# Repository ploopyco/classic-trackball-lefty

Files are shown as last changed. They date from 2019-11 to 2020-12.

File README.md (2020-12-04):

# The Left-Handed Ploopy Trackball

By some stroke of luck, you've made your way here. The Ploopy Trackball. For left-handed people. Your life will never be the same.

This repository contains all of the design and production files necessary to make a Ploopy Trackball. For left-handed people. We've also included some kick-ass documentation in the Wiki on how to get it made, assemble it, and program it. (It's the same as our documentation for our right-handed trackball. You can find it [here](https://github.com/ploopyco/mouse/wiki).)

What are you waiting for? Your new life awaits.

Did I mention that this is for left-handed people? Because HELL YEAH, it is.

## QMK Firmware

If you're looking for a hex file containing working QMK code with a keymapping compatible with VIA, look in the firmware directory.

## Schematics

Note that the schematics are the same as the right-handed version of this mouse, so the revision number will say RX.XXX, not LX.XXX. This is intentional: the mice are schematically identical, and only the layout of the PCBs is different.

## Under what license is this released?

The firmware is released under GPLv3. The hardware is released under OHL CERN v1.2. Check the respective directories for full license text.

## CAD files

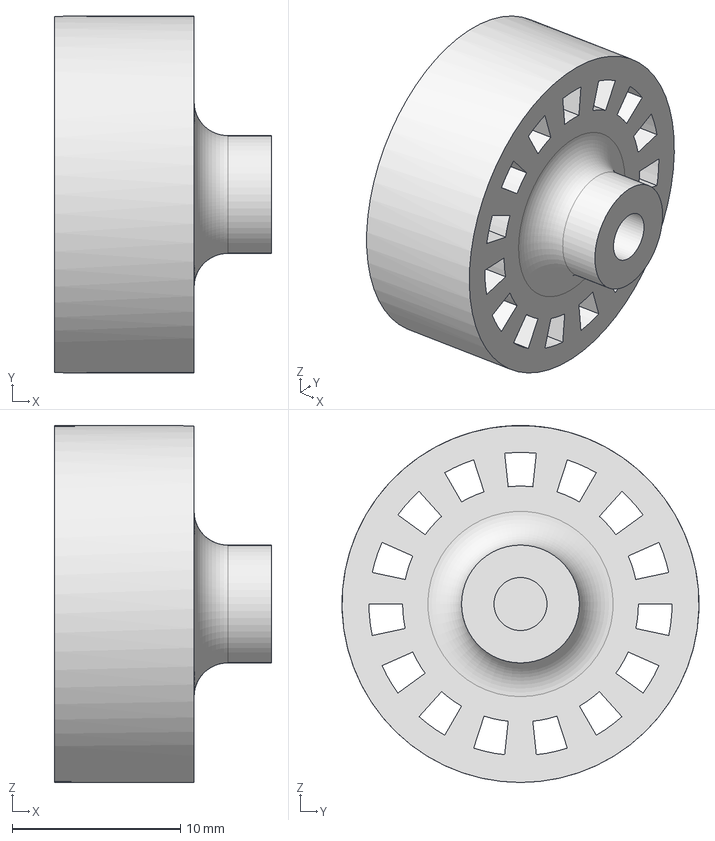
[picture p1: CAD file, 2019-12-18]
hardware/Mechanicals/STEPs/ScrollWheel.stp
12.9 x 21.2 x 21.2 mm

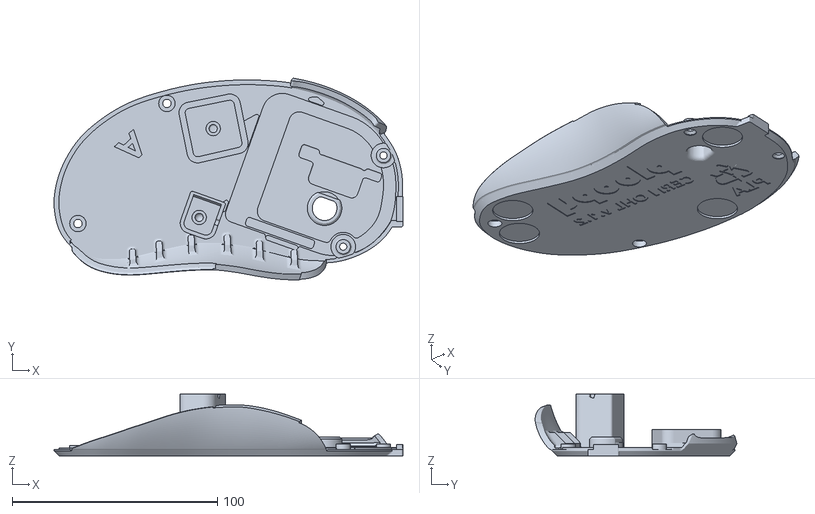
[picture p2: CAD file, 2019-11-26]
hardware/Mechanicals/STLs/Base-Lefty.stl
170.0 x 98.3 x 30.0

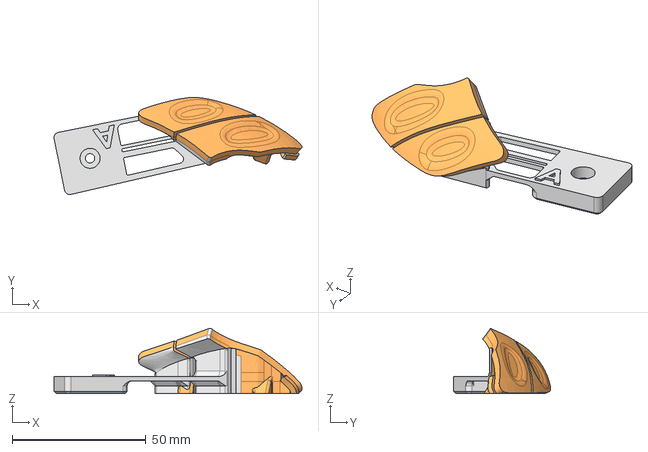
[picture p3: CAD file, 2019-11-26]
hardware/Mechanicals/STEPs/Secondary Buttons-Lefty.stp
92.8 x 36.3 x 24.3 mm

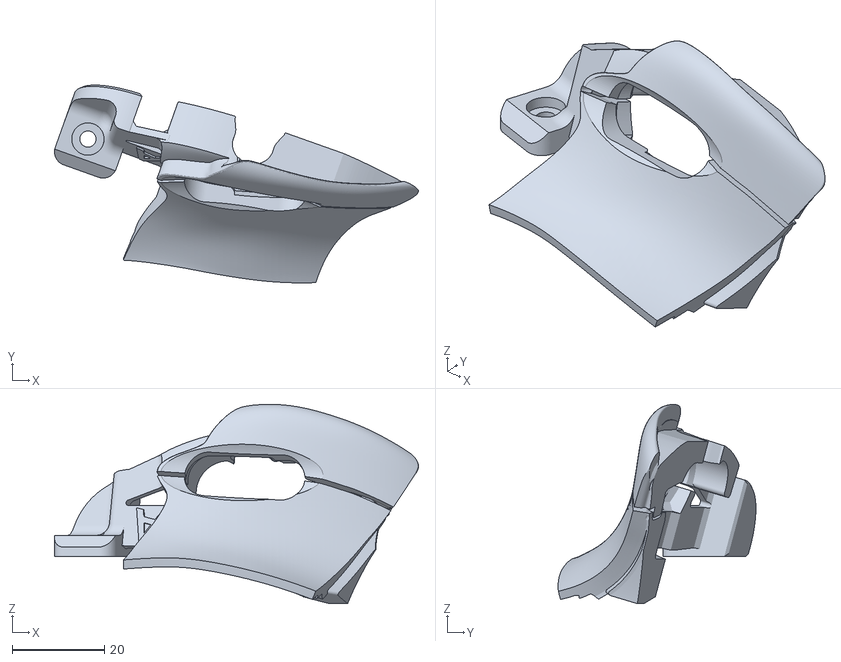
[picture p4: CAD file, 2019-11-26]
hardware/Mechanicals/STLs/Primary Buttons-Lefty.stl
78.9 x 42.9 x 43.2

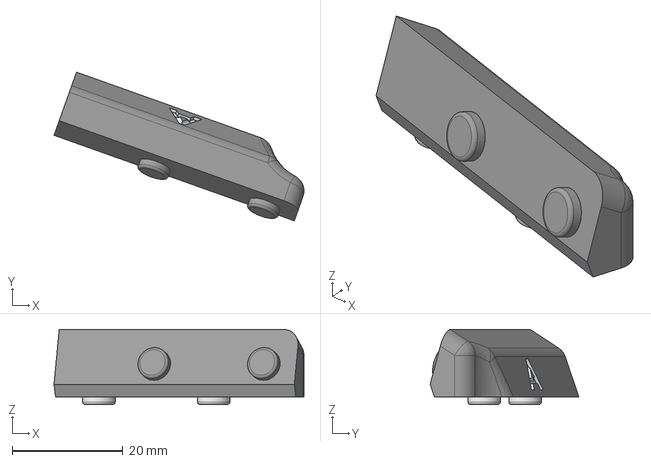
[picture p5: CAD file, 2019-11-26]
hardware/Mechanicals/STEPs/PCB Anchor-Lefty.stp
45.1 x 26.9 x 13.6 mm

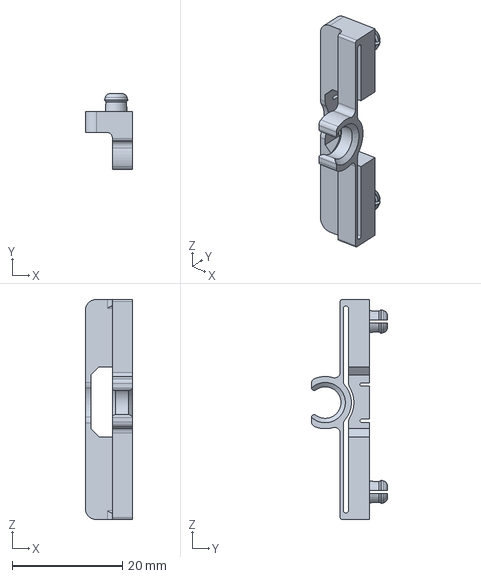
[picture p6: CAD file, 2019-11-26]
hardware/Mechanicals/STEPs/ScrollWheelHolderHolder-Lefty.stp
8.60 x 13.8 x 39.9 mm

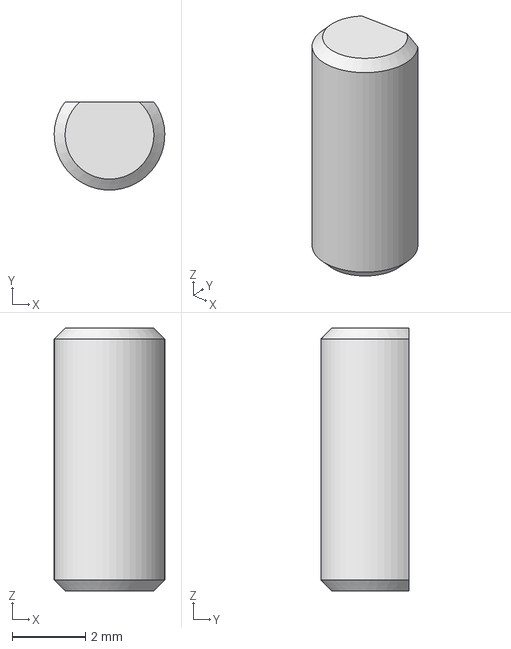
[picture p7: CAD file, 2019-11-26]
hardware/Mechanicals/STEPs/RollerBearingDowel.stp
3.03 x 2.42 x 7.20 mm

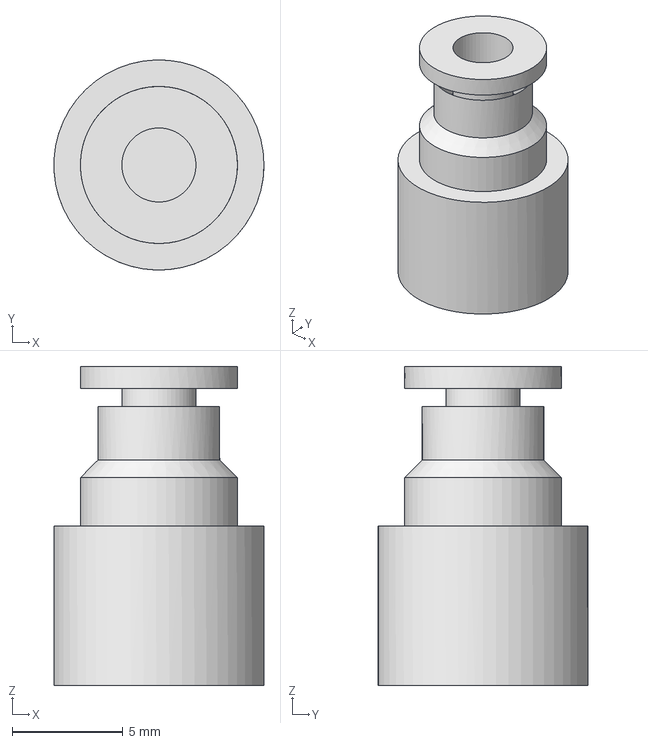
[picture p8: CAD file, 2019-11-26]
hardware/Mechanicals/STEPs/ScrollWheelHolder.stp
9.49 x 9.50 x 14.4 mm

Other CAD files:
hardware/Mechanicals/STLs/PCB Anchor-Lefty.stl
hardware/Mechanicals/STLs/RollerBearingDowel.stl
hardware/Mechanicals/STLs/ScrollWheel.stl
hardware/Mechanicals/STLs/ScrollWheelHolder.stl
hardware/Mechanicals/STLs/ScrollWheelHolderHolder-Lefty.stl
hardware/Mechanicals/STLs/Secondary Buttons-Lefty.stl

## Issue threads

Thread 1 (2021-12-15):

precompiled firmware config

vly, 2021-12-15:
Hey there,
Would you be able to provide the settings used for the compiled qmk hex file you distributed please?

I tried compiling rev1 but the buttons mapping is off (and the scrolling gets wonky) with the image I ended up building so assume the lefty version settings differ?

Also, VIA doesn't appear to detect the device. Any suggestions on what can be done here?

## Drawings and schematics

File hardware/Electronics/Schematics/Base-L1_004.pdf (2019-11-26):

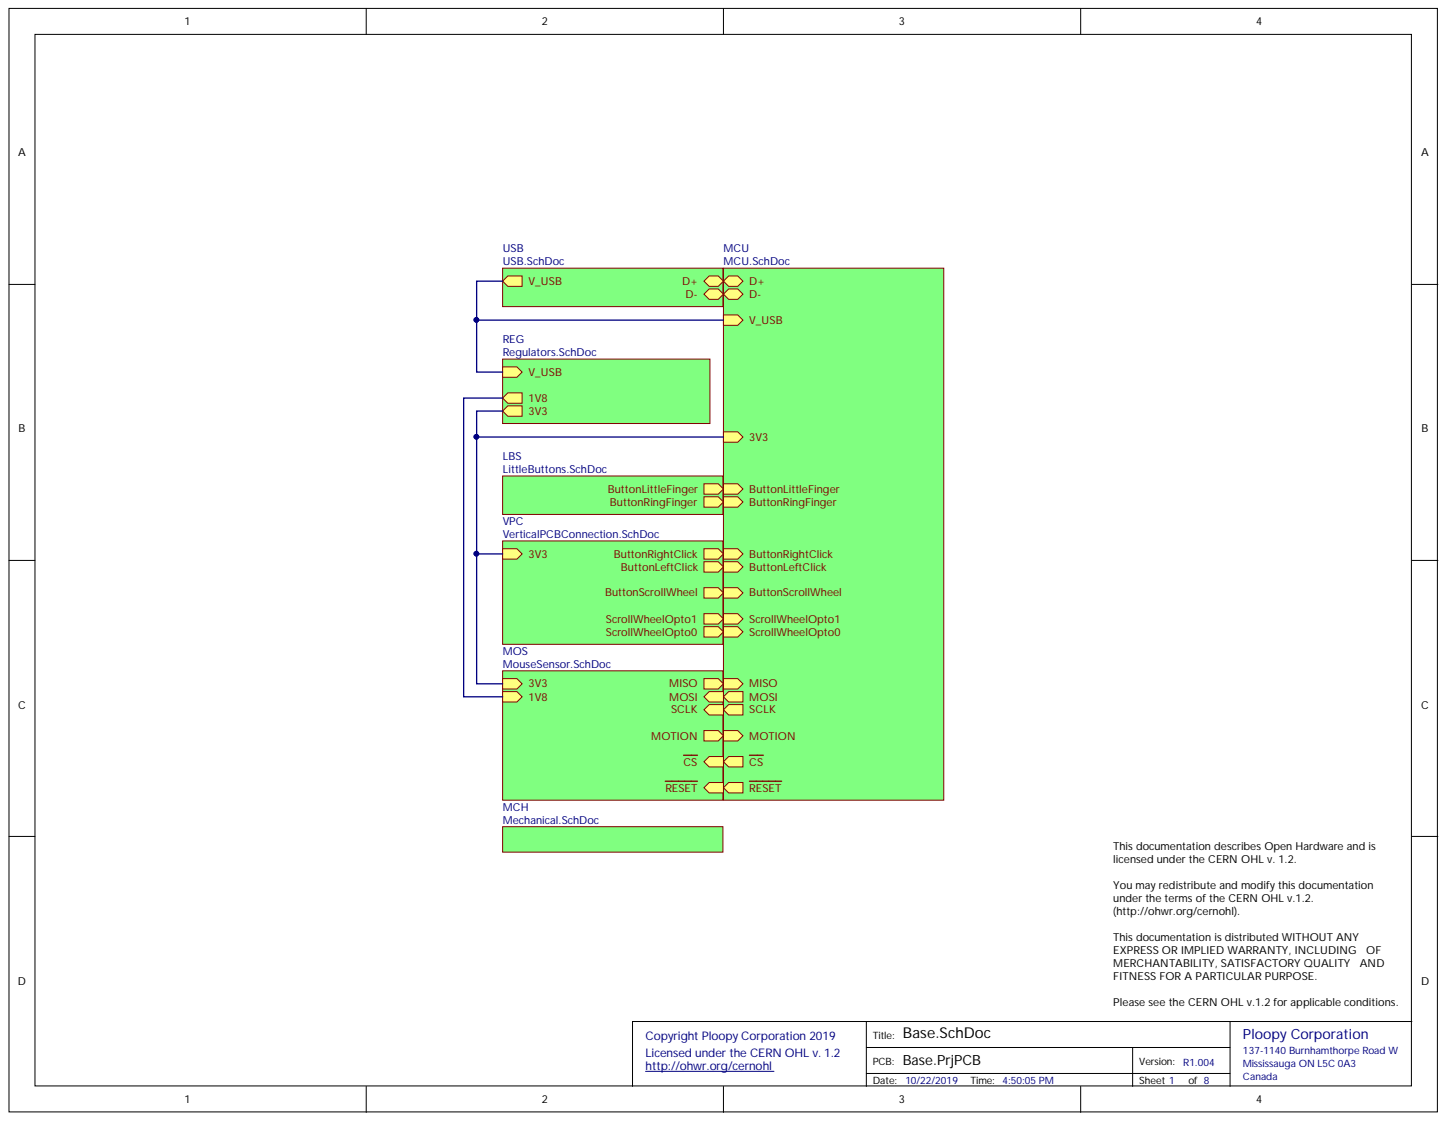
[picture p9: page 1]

This documentation describes Open Hardware and is
licensed under the CERN OHL v. 1.2.

You may redistribute and modify this documentation
under the terms of the CERN OHL v.1.2.
(http://ohwr.org/cernohl).

This documentation is distributed WITHOUT ANY
EXPRESS OR IMPLIED WARRANTY, INCLUDING OF
MERCHANTABILITY, SATISFACTORY QUALITY AND
FITNESS FOR A PARTICULAR PURPOSE.

Please see the CERN OHL v.1.2 for applicable conditions.

Copyright Ploopy Corporation 2019 Licensed under the CERN OHL v. 1.2 http://ohwr.org/cernohl | Title: Base.SchDoc | Ploopy Corporation 137-1140 Burnhamthorpe Road W Mississauga ON L5C 0A3 Canada

PCB: Base.PrjPCB | Version: R1.004

Date: 10/22/2019 Time: 4:50:05 PM | Sheet of

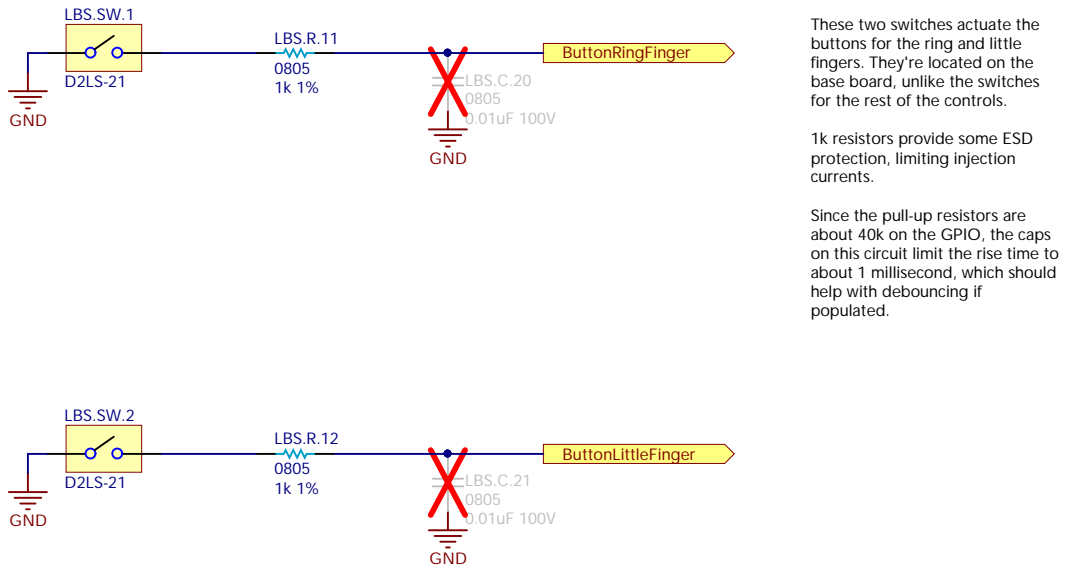
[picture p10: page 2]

These two switches actuate the
buttons for the ring and little
fingers. They're located on the
base board, unlike the switches
for the rest of the controls.

1k resistors provide some ESD
protection, limiting injection
currents.

Since the pull-up resistors are
about 40k on the GPIO, the caps
on this circuit limit the rise time to
about 1 millisecond, which should
help with debouncing if
populated.

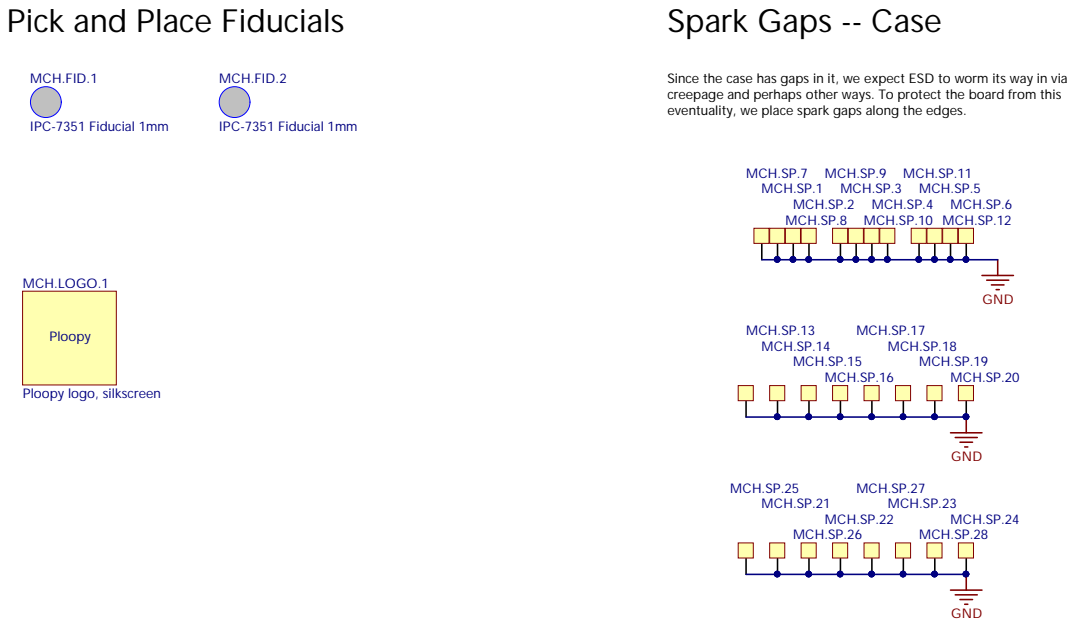
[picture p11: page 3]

Pick and Place Fiducials

Spark Gaps -- Case MCH.SP.7 MCH.SP.1 MCH.SP.8 MCH.SP.2 MCH.SP.9 MCH.SP.3 MCH.SP.10 MCH.SP.4 MCH.SP.11 MCH.SP.5 MCH.SP.12 MCH.SP.6 MCH.SP.13 MCH.SP.14 MCH.SP.15 MCH.SP.16 MCH.SP.17 MCH.SP.18 MCH.SP.19 MCH.SP.20

Since the case has gap
creepage and perhap
eventuality, we place s

s other ways. To protect the board from this
park gap

pect ESD to worm its way in via

CH.SP.25 MCH.SP.21 MCH.SP.26 MCH.SP.22 MCH.SP.27 MCH.SP.23 MCH.SP.28 MCH.SP.24 GND GND

Cop yri ght Ploop y Corporation 2019 Licensed under the CE R N OHL v . 1. http : //ohwr.org /cernohl | Mechanic al.SchDoc | Ploopy Corporation Mississauga ON L5C 0A3 137-1140 Burnhamthorpe Road W

PCB : Base.PrjPC B | Versi on:

10/22/2019 Ti me: 4:50:05 P M | Sheet o f

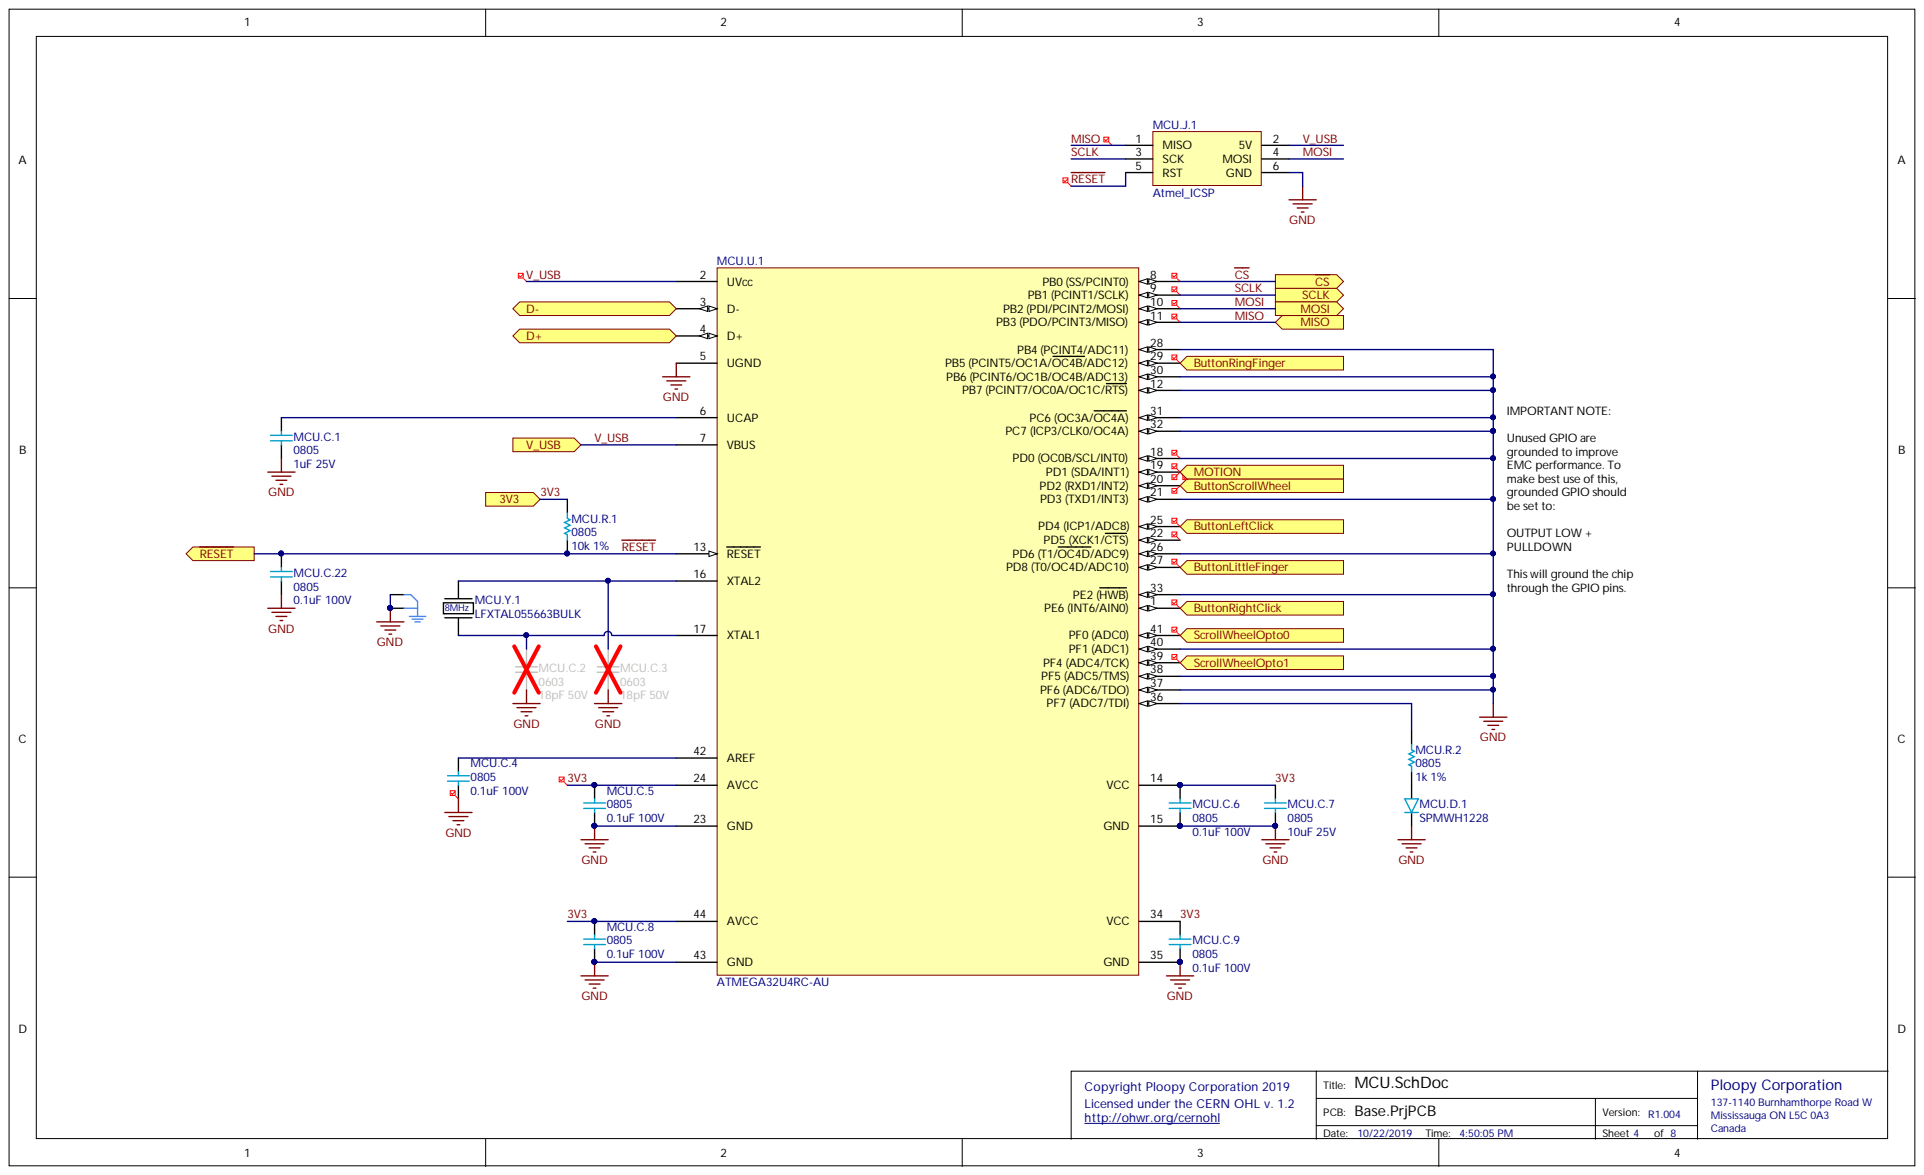
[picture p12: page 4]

performance.
best use of thi
GPI

C opy righ t Plo opy C o rpo ratio n 2 0 1 9 Lice n sed u nde r t h e CERN O HL v. 1.2 h t tp://o hwr.o rg/ce r n o h l | T i t le: MCU.SchDoc | Ploop y Corporation 137-1140 Burnha m tho rpe Ro ad W M i s s i s s auga ON L5C 0A 3 C anada

Base.PrjPC B P C B : | Vers i on: R1.004

D a te: 10/22/2019 T i me: 4:50:05 P M | Sheet 4 o f 8

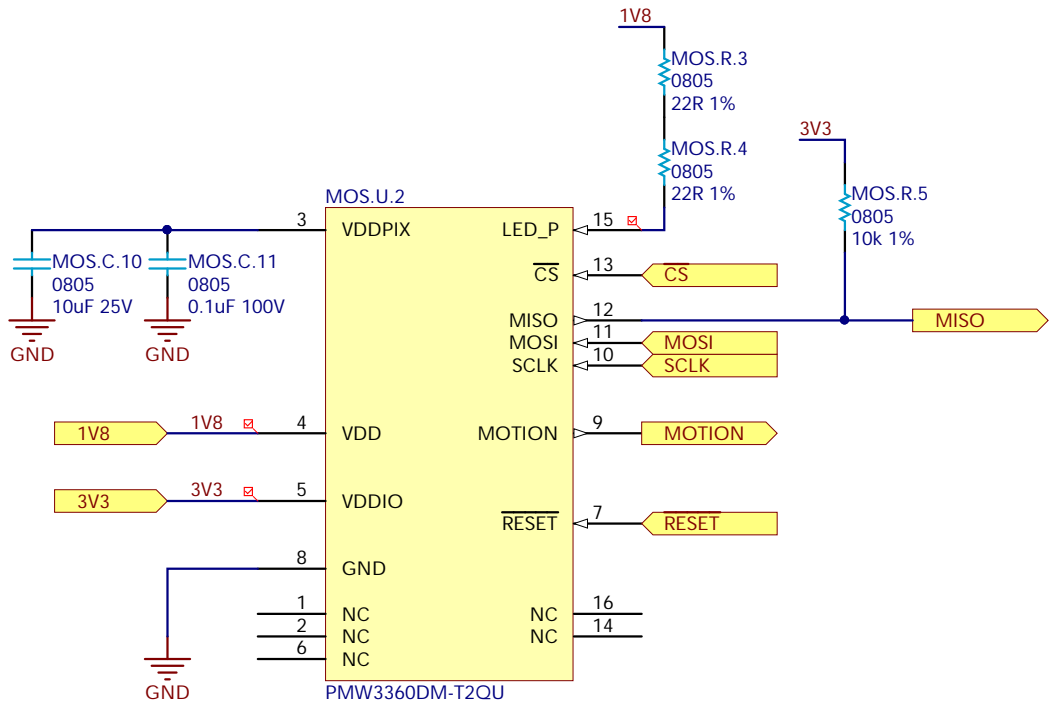
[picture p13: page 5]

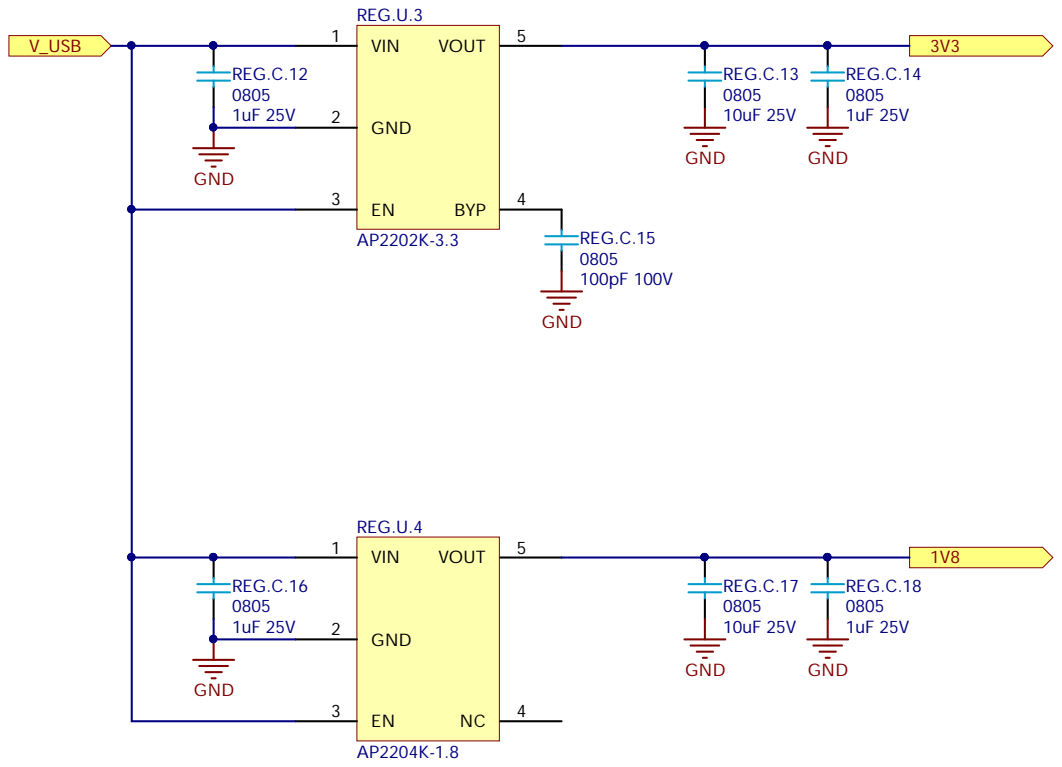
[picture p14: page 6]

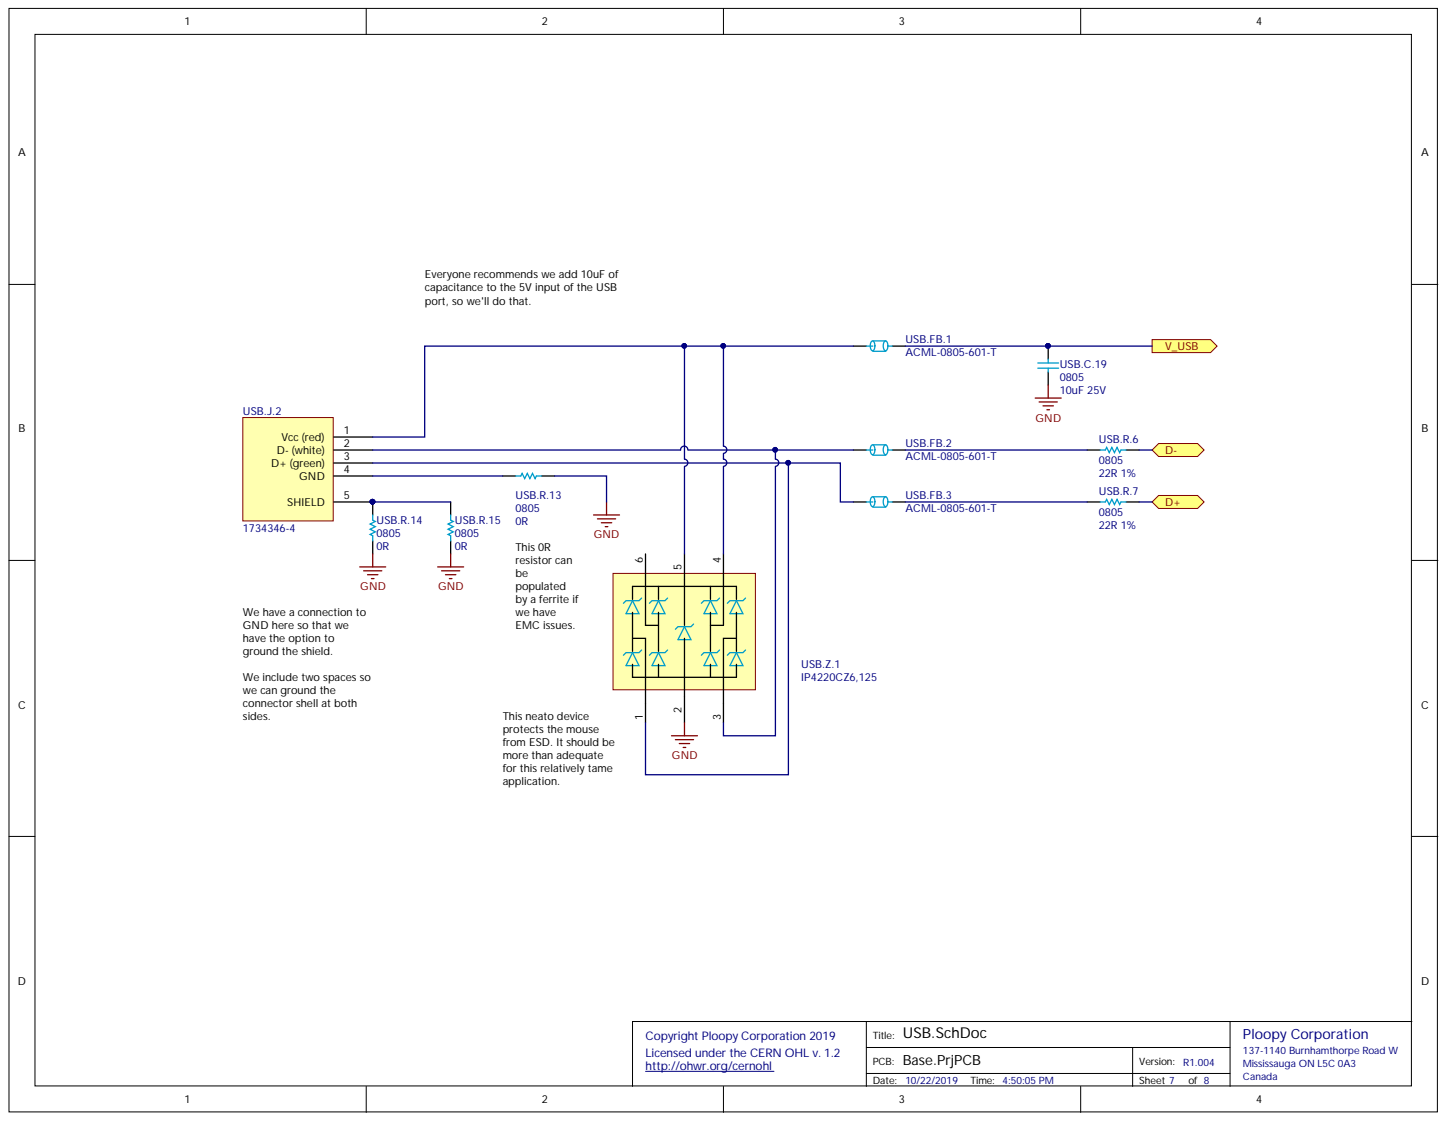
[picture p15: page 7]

capacitance to the 5V input of the USB port, so we'll do that. This neato device protects the mouse

This 0R
resistor can be populated by a ferrite if we have

We have a connection to GND here so that we

have the option to ground the shield.

We include two s
we can ground the
connector shell at both sides.

from ESD. It should be more than adequate

for this relatively tame

Cop yri ght Ploop y Corporation 2019 Licensed under the CE R N OHL v . 1. http : //ohwr.org /cernohl | USB .SchDoc | Ploopy Corporation Mississauga ON L5C 0A3 137-1140 Burnhamthorpe Road W

PCB : Base.PrjPC B | Versi on:

10/22/2019 Ti me: 4:50:05 P M | Sheet o f

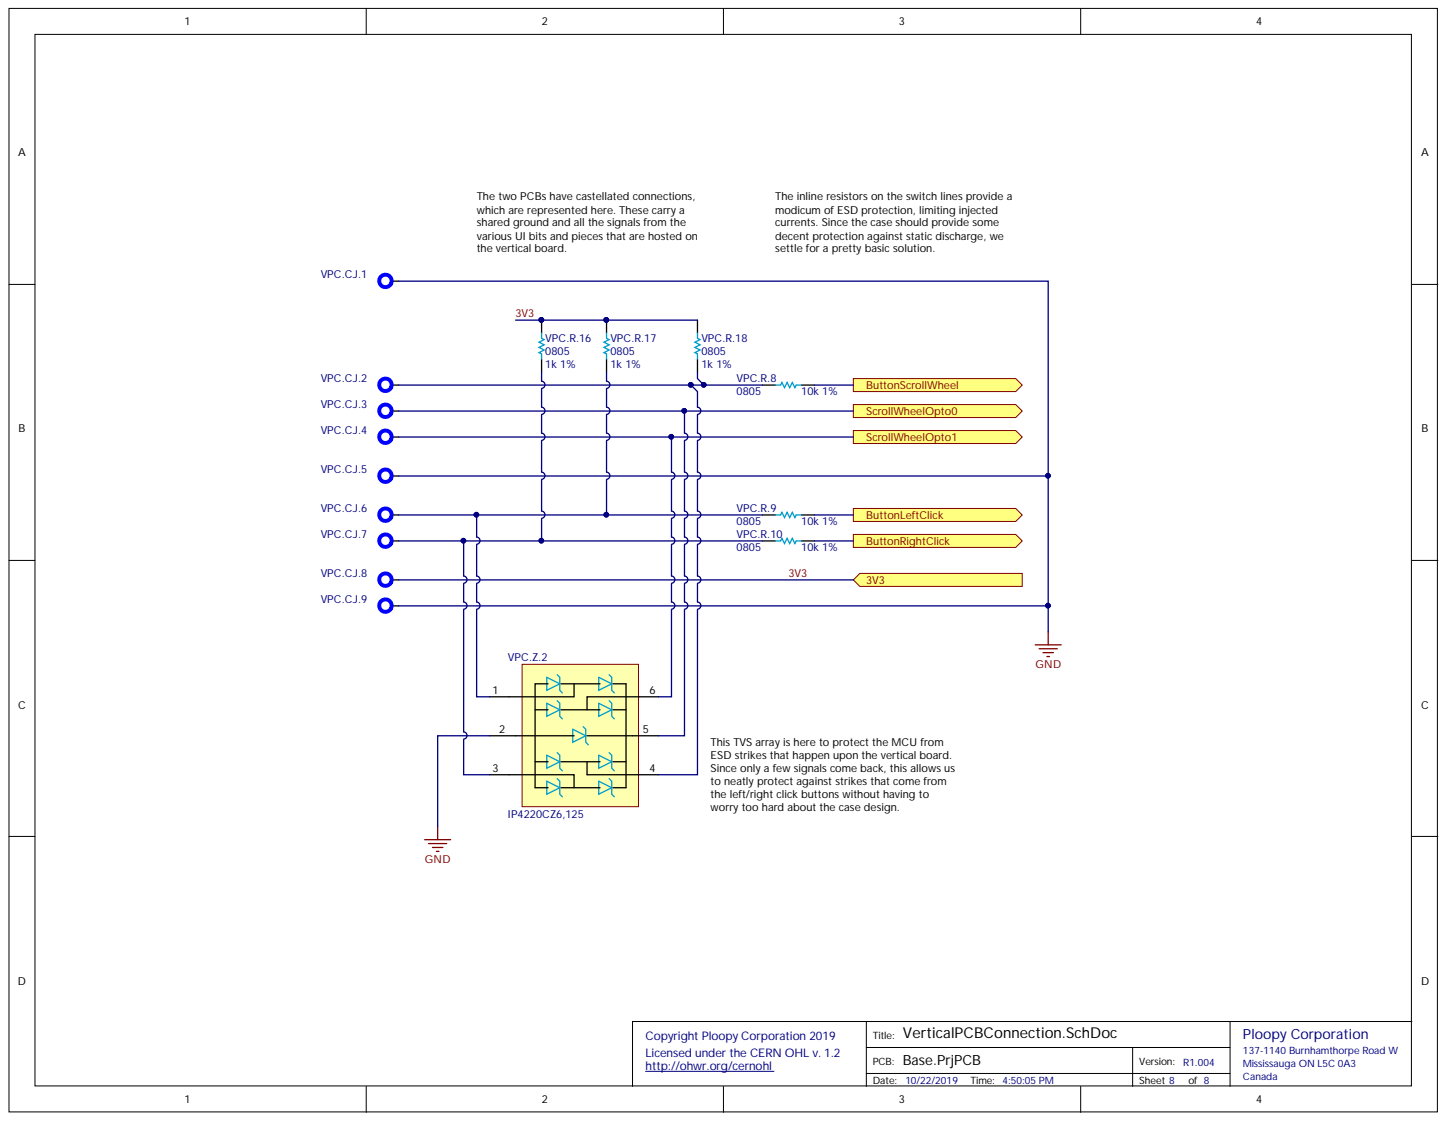
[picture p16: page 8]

The two PCBs have castellated connections,
which are represented here. These carry a
shared ground and all the signals from the
various UI bits and pieces that are hosted on
the vertical board.

The inline resistors on the switch lines provide a
modicum of ESD protection, limiting injected
currents. Since the case should provide some
decent protection against static discharge, we
settle for a pretty basic solution.

VPC.R.9 3V3
0805 VPC.R.10

This TVS array is here to protect the MCU from
ESD strikes that happen upon the vertical board.
Since only a few signals come back, this allows us
to neatly protect against strikes that come from
the left/right click buttons without having to
worry too hard about the case design.

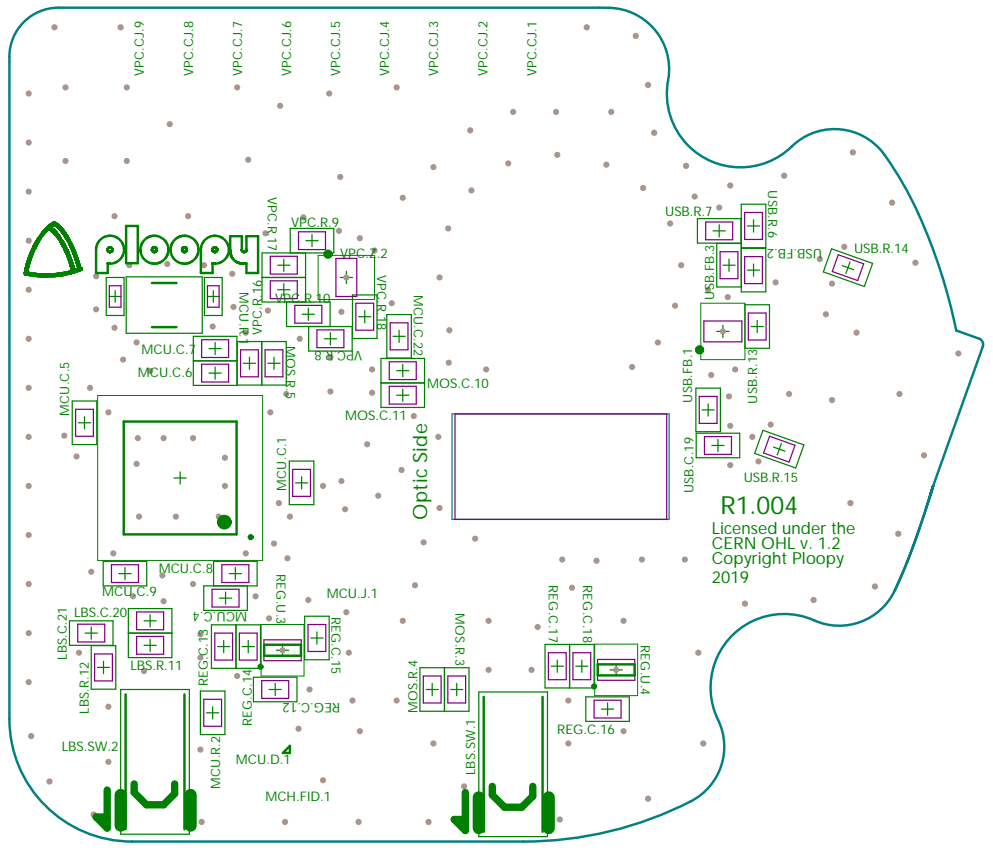
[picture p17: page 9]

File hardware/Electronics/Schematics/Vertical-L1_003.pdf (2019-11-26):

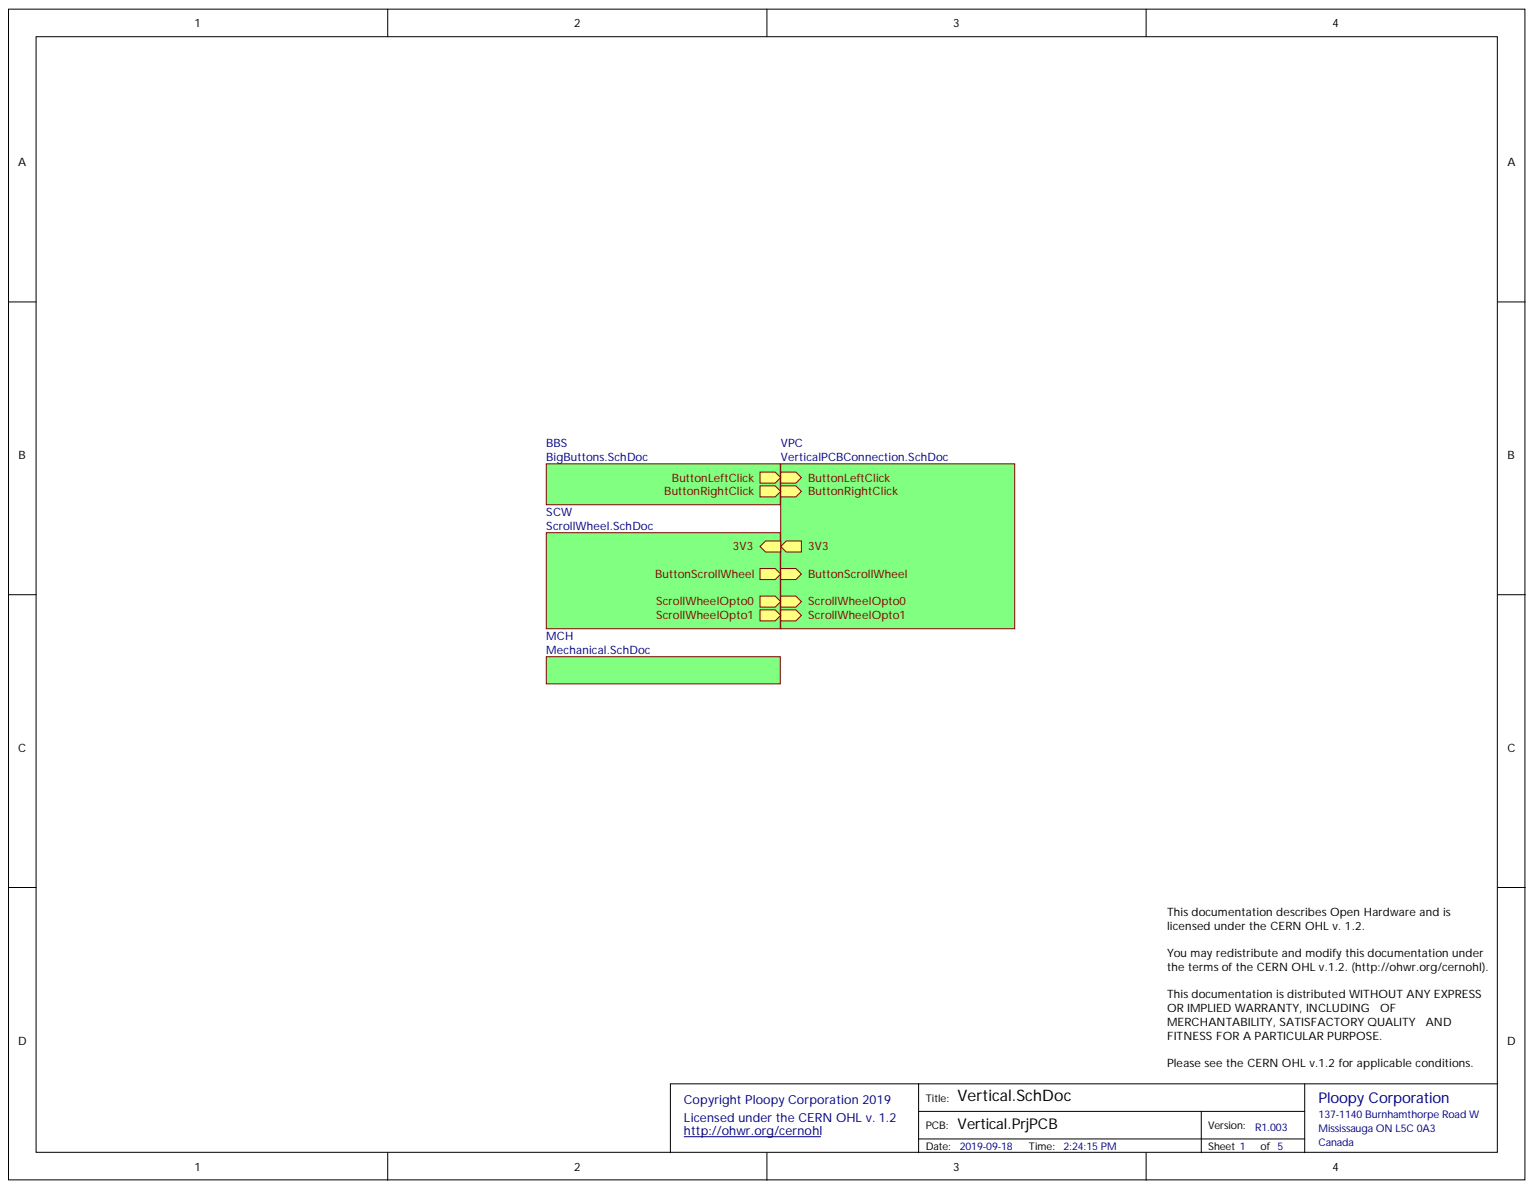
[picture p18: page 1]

This documentation describes Open Hardware and is
licensed under the CERN OHL v. 1.2.

You may redistribute and modify this documentation under
the terms of the CERN OHL v.1.2. (http://ohwr.org/cernohl).

This documentation is distributed WITHOUT ANY EXPRESS
OR IMPLIED WARRANTY, INCLUDING OF
MERCHANTABILITY, SATISFACTORY QUALITY AND
FITNESS FOR A PARTICULAR PURPOSE.

Please see the CERN OHL v.1.2 for applicable conditions.

Copyright Ploopy Corporation 2019 Licensed under the CERN OHL v. 1.2 http://ohwr.org/cernohl | Title: Vertical.SchDoc | Ploopy Corporation 137-1140 Burnhamthorpe Road W Mississauga ON L5C 0A3 Canada

PCB: Vertical.PrjPCB | Version: R1.003

Date: 2019-09-18 Time: 2:24:15 PM | Sheet of

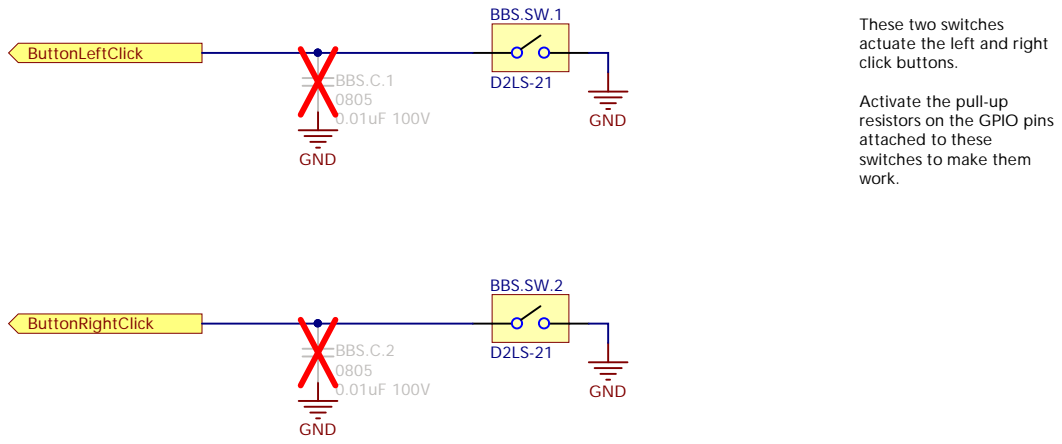
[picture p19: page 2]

These two switches
actuate the left and right
click buttons.

Activate the pull-up
resistors on the GPIO pins
attached to these
switches to make them
work.

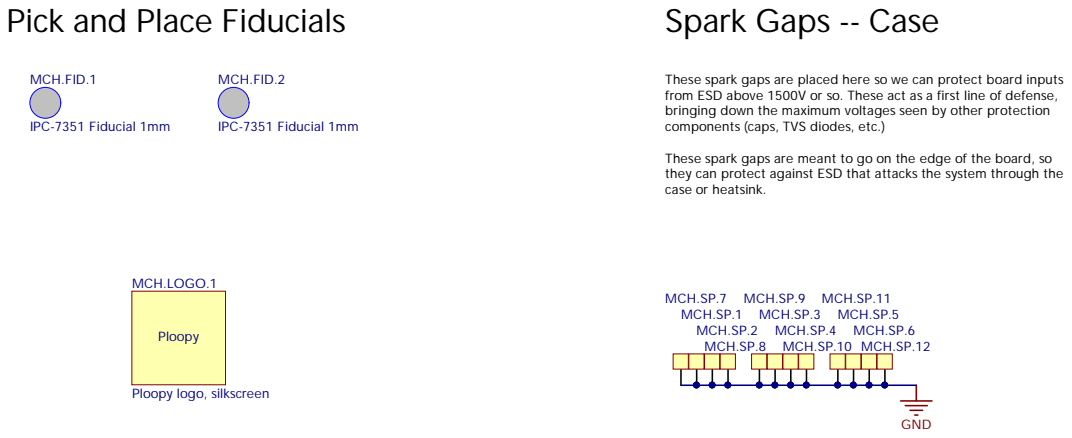
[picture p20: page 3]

Pick and Place Fiducials

These spark gaps are placed here so we can protect board inputs
from ESD above 1500V or so. These act as a first line of defense,
bringing down the maximum voltages seen by other protection
components (caps, TVS diodes, etc.)

These spark gaps are meant to go on the edge of the board, so
they can protect against ESD that attacks the system through the
case or heatsink.


The button is pretty straightforward: when the
scroll wheel gets pressed, the button is
pressed.

To make this work, the pull-up resistor on the
GPIO pin it's attached to needs to be
activated.

The scroll wheel mechanism is a 2-bit optical
encoder. The light paths are spaced 1.5
periods over the encoder wheel holes, which
should allow for the detection of the rotation
direction as well as the rotation itself.

Two IR LEDs are used as light sources; the light
from these is obstructed by the encoder wheel
built into the scroll wheel mechanism. Two
phototransistors are used to detect when the
light is blocked/not blocked by the wheel.

Typical LED forward voltage is 1.3V @20mA.
To achieve this current level with a 3.3V
supply, we'll use a 100R resistor, which is very
convenient.

At this power level, the output should be
approx 2.3mW/sr.

Since the light path distance is about 12mm,
that works out to about 2mW/cm^2, though
the actual delivered power will be lower due to
the vagaries of the obstructions in the
mechanism.

With this amount of light (and accounting for
the fact that we'll probably lose a lot of it
along the way), we are expecting 1-3mA out of
the phototransistor (see figure 6 of the
datasheet), so we size the biasing resistor
accordingly to produce a useful signal.


The two PCBs have
castellated connections,
which are represented here.
These carry a shared ground
and all the signals from the
various UI bits and pieces
that are hosted on the
vertical board.


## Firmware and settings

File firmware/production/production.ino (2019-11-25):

/*
 * Copyright (c) 2019, Ploopy Corporation, a Canadian federal corporation.
 *
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
 * You should have received a copy of the GNU General Public License
 * along with this program; if not, write to the Free Software
 * Foundation, Inc.
 * 51 Franklin St, Fifth Floor, Boston, MA  02110-1301  USA
 */

#include <SPI.h>
#include <avr/pgmspace.h>
#include <avr/wdt.h>
#include "AdvMouse.h"
#include "Scroller.h"

// Max recommended is 4,000,000, since clock speed is 8MHz.
// If lower, it should be by factors of 1/2.
static const int SPIMAXIMUMSPEED = 2000000;

static const int CPI = 1200;
static const int DEBOUNCE = 10; // ms
static const int SCROLL_DEBOUNCE = 100; // ms
static const int SCROLL_BUTT_DEBOUNCE = 100; // ms

static const int8_t ROTATIONAL_TRANSFORM_ANGLE = -20;

static const int MOUSE_LEFT_PIN = 4;
static const int MOUSE_RIGHT_PIN = 7;
static const int MOUSE_MIDDLE_PIN = 0;
static const int MOUSE_BACK_PIN = 6;
static const int MOUSE_FORWARD_PIN = 9;

// For info, see https://forum.arduino.cc/index.php?topic=241369.0
static const int SENSOR_CS = 17;

static const int OPT_ENC_PIN1 = A3;
static const int OPT_ENC_PIN2 = A5;

static const byte MOTION = 0x02;
static const byte DELTA_X_L = 0x03;
static const byte DELTA_X_H = 0x04;
static const byte DELTA_Y_L = 0x05;
static const byte DELTA_Y_H = 0x06;
static const byte CONFIG1 = 0x0F;
static const byte CONFIG2 = 0x10;
static const byte ANGLE_TUNE = 0x11;
static const byte SROM_ENABLE = 0x13;
static const byte SROM_ID = 0x2A;
static const byte POWER_UP_RESET = 0x3A;
static const byte SHUTDOWN = 0x3B;
static const byte MOTION_BURST = 0x50;
static const byte SROM_LOAD_BURST = 0x62;

boolean debugMode = false;
boolean wdtMode = false;

int buttonPin[5] = { MOUSE_LEFT_PIN, MOUSE_RIGHT_PIN, MOUSE_MIDDLE_PIN, MOUSE_BACK_PIN, MOUSE_FORWARD_PIN };
bool buttonState[5] = { false, false, false, false, false };
uint8_t buttonBuffer[5] = { 0xFF, 0xFF, 0xFF, 0xFF, 0xFF };
char buttonKey[5] = { MOUSE_LEFT, MOUSE_RIGHT, MOUSE_MIDDLE, MOUSE_BACK, MOUSE_FORWARD };

bool initComplete = false;

int16_t dx;
int16_t dy;

unsigned long lastTS;
unsigned long lastButtonCheck = 0;

unsigned long lastScroll = 0;

unsigned long middleClickRelease = 0;

static Scroller scroller;

extern const unsigned short firmware_length;
extern const unsigned char firmware_data[];

void setup() {
  if (wdtMode) {
    setupWDT();
  }

  if (debugMode) {
    Serial.begin(9600);
  }

  // Startup delay. This sometimes prevents a USB handshake lockup.
  delay(1000);

  setupPins();

  // This is the debug LED.
  pinMode(A0, OUTPUT);
  if (debugMode) {
    digitalWrite(A0, HIGH);
  } else {
    digitalWrite(A0, LOW);
  }

  SPI.begin();
  SPI.setDataMode(SPI_MODE3);
  SPI.setBitOrder(MSBFIRST);

  initialisePMW3360();

  dx = 0;
  dy = 0;

  delay(1000);

  initComplete = true;

  lastTS = micros();

  AdvMouse.begin();

  if (debugMode) {
    Serial.println(F("end setup"));
  }
}

void setupWDT() {
  /* IMPORTANT NOTE!
   * THIS MUST BE THE FIRST THING THAT RUNS IN SETUP()! If it isn't, there's
   * a good chance the Arduino will enter an unstable state, and it's entirely
   * possible that you can permanently brick your MCU!
   */

  cli();

  // Clear the watchdog reset flag
  MCUSR &= ~(1 << WDRF);

  // Enter watchdog configuration mode
  WDTCSR |= (1 << WDCE) |
            (1 << WDE);

  // WDIE needs to be included, or else this doesn't work.
  WDTCSR = (1 << WDIE) |
           (1 << WDE) |
           (1 << WDP3) |
           (0 << WDP2) |
           (0 << WDP1) |
           (0 << WDP0);

  sei();
}

void setupPins() {
  pinMode(SENSOR_CS, OUTPUT);
  pinMode(MOUSE_LEFT_PIN, INPUT_PULLUP);
  pinMode(MOUSE_RIGHT_PIN, INPUT_PULLUP);
  pinMode(MOUSE_MIDDLE_PIN, INPUT_PULLUP);
  pinMode(MOUSE_BACK_PIN, INPUT_PULLUP);
  pinMode(MOUSE_FORWARD_PIN, INPUT_PULLUP);

  pinMode(OPT_ENC_PIN1, INPUT);
  pinMode(OPT_ENC_PIN2, INPUT);

  /* Ground all output pins connected to ground. This provides additional
   * pathways to ground. If you're messing with this, know this: driving ANY
   * of these pins high will cause a short. On the MCU. Ka-blooey.
   */
  pinMode(1, OUTPUT);
  pinMode(2, OUTPUT);
  pinMode(8, OUTPUT);
  pinMode(10, OUTPUT);
  pinMode(11, OUTPUT);
  pinMode(12, OUTPUT);
  pinMode(13, OUTPUT);
  pinMode(A1, OUTPUT);
  pinMode(A2, OUTPUT);
  pinMode(A4, OUTPUT);
  digitalWrite(1, LOW);
  digitalWrite(2, LOW);
  digitalWrite(8, LOW);
  digitalWrite(10, LOW);
  digitalWrite(11, LOW);
  digitalWrite(12, LOW);
  digitalWrite(13, LOW);
  digitalWrite(A1, LOW);
  digitalWrite(A2, LOW);
  digitalWrite(A4, LOW);
}

void adnsComBegin() {
  digitalWrite(SENSOR_CS, LOW);
}

void adnsComEnd() {
  digitalWrite(SENSOR_CS, HIGH);
}

byte adnsReadReg(byte reg_addr) {
  adnsComBegin();

  // send adress of the register, with MSBit = 0 to indicate it's a read
  SPI.transfer(reg_addr & 0x7f);
  delayMicroseconds(35); // tSRAD
  byte data = SPI.transfer(0);

  // tSCLK-SENSOR_CS for read operation is 120ns
  delayMicroseconds(1);
  adnsComEnd();
  // tSRW/tSRR (=20us) minus tSCLK-SENSOR_CS
  delayMicroseconds(19);

  return data;
}

void adnsWriteReg(byte reg_addr, byte data) {
  adnsComBegin();

  // send adress of the register, with MSBit = 1 to indicate it's a write
  SPI.transfer(reg_addr | 0x80);
  SPI.transfer(data);

  // tSCLK-SENSOR_CS for write operation
  delayMicroseconds(20);
  adnsComEnd();
  // tSWW/tSWR (=120us) minus tSCLK-SENSOR_CS.
  // Could be shortened, but this looks like a safe lower-bound.
  delayMicroseconds(100);
}

void setCPI(int cpi) {
  int cpival = constrain((cpi / 100) - 1, 0, 0x77); // limits to 0--119

  adnsComBegin();
  adnsWriteReg(CONFIG1, cpival);
  adnsComEnd();

  if (debugMode) {
    Serial.print(F("Got "));
    Serial.println(cpi);
    Serial.print(F("Set cpi to "));
    Serial.println((cpival + 1) * 100);
  }
}

void initialisePMW3360(void) {
  if (debugMode) {
    Serial.println(F("Initialising PMW3360"));
  }

  // Hard reset. Start by ensuring that the serial port is reset.
  adnsComEnd();
  adnsComBegin();
  adnsComEnd();

  // SHUTDOWN the PMW3360, in case the microcontroller reset but the sensor didn't.
  adnsWriteReg(SHUTDOWN, 0xb6);
  delay(300);

  // Drop and raise SENSOR_CS to reset the spi port
  adnsComBegin();
  delayMicroseconds(40);
  adnsComEnd();
  delayMicroseconds(40);

  // Force a reset of the PMW3360.
  adnsWriteReg(POWER_UP_RESET, 0x5a);
  delay(50);

  // Read registers 0x02 through 0x06 (and discard the data)
  adnsReadReg(MOTION);
  adnsReadReg(DELTA_X_L);
  adnsReadReg(DELTA_X_H);
  adnsReadReg(DELTA_Y_L);
  adnsReadReg(DELTA_Y_H);

  if (debugMode) {
    Serial.println(F("Uploading firmware to PMW3360"));
  }

  // Write 0 to Rest_En bit of CONFIG2 register to disable Rest mode.
  adnsWriteReg(CONFIG2, 0x00);

  // write 0x1d in SROM_enable reg for initializing
  adnsWriteReg(SROM_ENABLE, 0x1d);

  // wait for more than one frame period
  // assume that the frame rate is as low as 100fps, even if it should never be that low
  delay(10);

  // write 0x18 to SROM_enable to start SROM download
  adnsWriteReg(SROM_ENABLE, 0x18);

  // write burst destination adress
  adnsComBegin();
  SPI.transfer(SROM_LOAD_BURST | 0x80);
  delayMicroseconds(15);

  unsigned char c;
  for (int i = 0; i < firmware_length; i++) {
    c = (unsigned char) pgm_read_byte(firmware_data + i);
    SPI.transfer(c);
    delayMicroseconds(15);
  }

  // Read the SROM_ID register to verify the ID before any other register reads or writes.
  adnsReadReg(SROM_ID);

  // Write 0x00 (rest disable) to CONFIG2 register for wired mouse.
  // (If this were a wireless design, it'd be 0x20.)
  adnsWriteReg(CONFIG2, 0x00);

  // Rotate the x and y results, since the sensor isn't quite squared up in
  // the enclosure.
  // Sensor rotates up to +/-30 degrees
  adnsWriteReg(ANGLE_TUNE, constrain(ROTATIONAL_TRANSFORM_ANGLE, -30, 30));

  adnsComEnd();

  if (debugMode) {
    Serial.println(F("Firmware successfully written to PMW3360"));
  }

  delay(10);

  setCPI(CPI);

  // start burst mode
  adnsWriteReg(MOTION_BURST, 0x00);

  if (debugMode) {
    Serial.println(F("PMW3360 successfully initialized"));
  }
}


void checkButtonState() {
  if (!initComplete)
    return;

  unsigned long elapsed = micros() - lastButtonCheck;

  // Update at a period of 1/8 of the DEBOUNCE time
  if (elapsed < (DEBOUNCE * 1000UL / 8)) {
    return;
  }

  lastButtonCheck = micros();

  // Fast debounce (works with 0 latency most of the time)
  for (int i = 0; i < 5; i++) {
    int curButtonState = digitalRead(buttonPin[i]);
    buttonBuffer[i] = buttonBuffer[i] << 1 | curButtonState;

    if (!buttonState[i] && buttonBuffer[i] == 0xFE) {
      // First time the button press is being registered.
      AdvMouse.press_(buttonKey[i]);
      buttonState[i] = true;
    } else if ((buttonState[i] && buttonBuffer[i] == 0x01) ||
               (buttonState[i] && buttonBuffer[i] == 0xFF)) {
      // Either the button is being released, or the debounce time elapsed.
      AdvMouse.release_(buttonKey[i]);
      buttonState[i] = false;

      if (buttonPin[i] == MOUSE_MIDDLE_PIN) {
        middleClickRelease = micros();
      }
    }
  }
}

signed char moveWheel() {
  // If the mouse wheel was just released, do not scroll.
  unsigned long elapsed = micros() - middleClickRelease;
  if (elapsed < SCROLL_BUTT_DEBOUNCE) {
    return 0;
  }

  // Limit the number of scrolls per unit time.
  elapsed = micros() - lastScroll;
  if (elapsed < SCROLL_DEBOUNCE) {
    return 0;
  }

  // Don't scroll if the middle button is depressed.
  int middleButtonPin = digitalRead(MOUSE_MIDDLE_PIN);
  if (middleButtonPin == LOW) {
    return 0;
  }

  lastScroll = micros();

  int d1 = analogRead(OPT_ENC_PIN1);
  int d2 = analogRead(OPT_ENC_PIN2);

  if (debugMode) {
    scroller.debug();
    Serial.print(F(", d1: "));
    Serial.print(d1);
    Serial.print(F(", d2: "));
    Serial.println(d2);
  }

  return scroller.scroll(d2, d1);
}

void loop() {
  if (wdtMode) {
    wdt_reset();
  }

  byte burstBuffer[12];
  unsigned long curTime = micros();
  unsigned long elapsed = curTime - lastTS;

  checkButtonState();

  // polling interval : more than > 0.5 ms.
  if (elapsed >= 1000) {
    adnsComBegin();
    SPI.beginTransaction(SPISettings(SPIMAXIMUMSPEED, MSBFIRST, SPI_MODE3));

    SPI.transfer(MOTION_BURST);
    // Wait for tSRAD
    delayMicroseconds(35);

    // read burst buffer
    SPI.transfer(burstBuffer, 12);
    // tSCLK-SENSOR_CS for read operation is 120ns
    delayMicroseconds(1);

    SPI.endTransaction();

    int motion = (burstBuffer[0] & 0x80) > 0;

    int xl = burstBuffer[2];
    int xh = burstBuffer[3];
    int yl = burstBuffer[4];
    int yh = burstBuffer[5];

    int x = xh << 8 | xl;
    int y = yh << 8 | yl;

    dx -= x;
    dy += y;

    adnsComEnd();

    signed char wheel = moveWheel();

    // update only if a movement is detected.
    if (AdvMouse.needSendReport() || motion || wheel != 0) {
      AdvMouse.move(dx, dy, wheel);
      dx = 0;
      dy = 0;
    }

    lastTS = curTime;
  }
}

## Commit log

2019-11-26 Added Rev A 3D printable files in STEP and STL format.
    [Base-Lefty.stl, PCB Anchor-Lefty.stl, PCB Anchor-Lefty.stp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]
2019-11-26 Added design files, gerbers, and PDF schematics for the leftie electronics.
    [Base.SchDoc, BigButtons.SchDoc, Chip_Passives.PcbLib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]
2019-11-26 Added a note about schematics to the readme.
2019-12-18 altered wheels to have 13 holes instead of 20
    [ScrollWheel.stl, ScrollWheel.stp]
2020-06-02 fixed buffer overflow bug for optical sensors

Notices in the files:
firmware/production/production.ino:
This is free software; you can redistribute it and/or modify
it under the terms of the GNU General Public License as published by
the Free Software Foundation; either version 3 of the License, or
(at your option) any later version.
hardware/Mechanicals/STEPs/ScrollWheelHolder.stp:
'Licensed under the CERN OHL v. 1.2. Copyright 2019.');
